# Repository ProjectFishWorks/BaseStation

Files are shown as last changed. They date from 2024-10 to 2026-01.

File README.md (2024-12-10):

# BaseStation

The base station acts as the controller for the Fish Sense system. It connects to the devices via CAN Bus, and provides power to them. It then connects to the web app over WiFi and the MQTT protocol. It also sends email alerts and provides a basic user interface using buttons, LEDs, a buzzer, and a display.

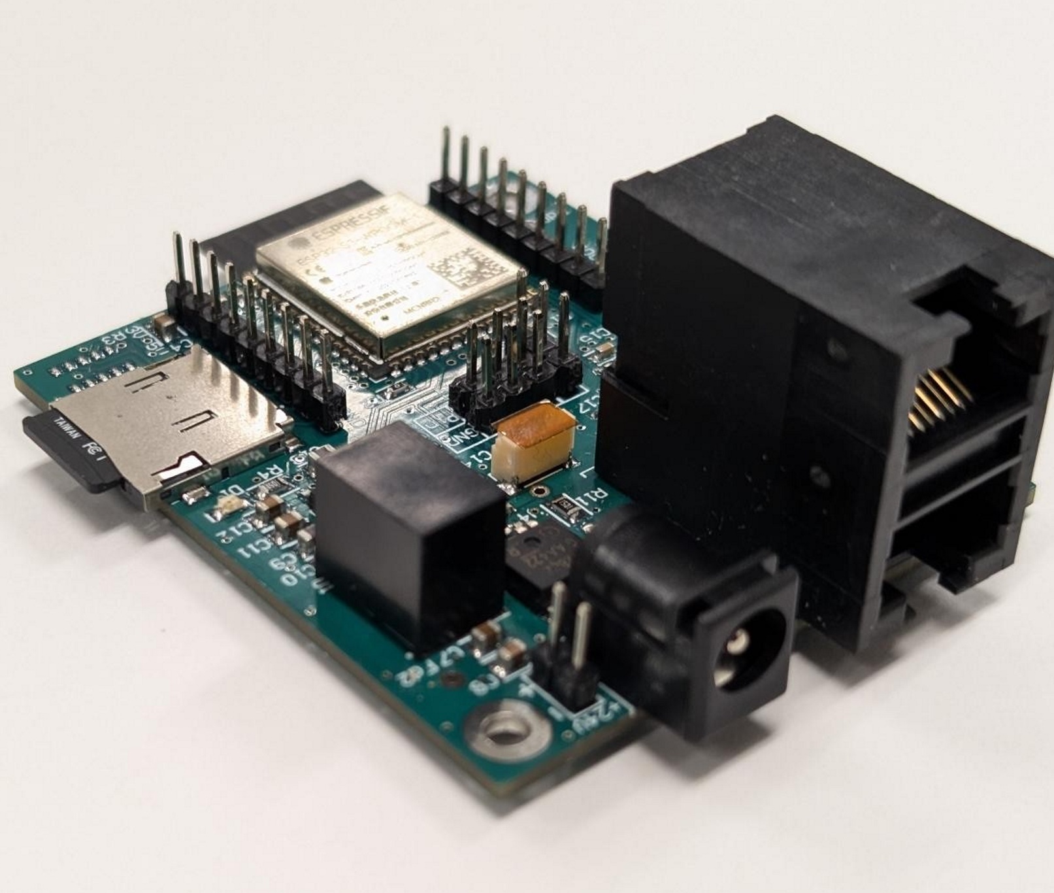
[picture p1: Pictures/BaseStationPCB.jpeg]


## Hardware

The base station is powered by the ESP32 S3 WROOM 1 module. The Microchip MCP2551 is used for the CAN Bus interface. Power is provided via a external 24V DC input. This 24V power is provided to the connected devices as well. The 24V going to the devices is switched to allow for controlled power up of the device network. It is also monitored using a current monitroing IC.

## MQTT CAN Bus data format

### Data outgoing from the base station

When data is received from the CAN Bus, it is sent to the web app over MQTT using the following format:

#### Topic:  
``` 
out/[System ID]/[Base Station ID]/[Node ID]/[Message ID] 
```

* System ID: The ID of the system/user. A system can contain several base stations.
* Base Station ID: The ID of the base station.
* Node ID: The ID of the node(attached to the base station) that the message is from.
* Message ID: A unique ID for the message type being sent.

#### Payload:  
``` 
{"data": [Data], "timestamp": [Timestamp]} 
```
* Data: The from the CAN Bus message.
* Timestamp: The time the message was received by the base station.

### Data incoming to the base station

When data is sent from the web app to the base station(to be sent to devices via CAN Bus), it is sent using the following format:

#### Topic:  
``` 
in/[System ID]/[Base Station ID]/[Node ID]/[Message ID] 
```

#### Payload:  
``` 
{"data": [Data], "timestamp": [Timestamp]} 
```

(Other JSON fields are added due to issues with the way the web app sends out MQTT data and are not used by the base station)

## MQTT History Request Format

The web app can request a specific numbers of hours(going back from the current time) for a specific node and message ID with the following format:

#### Topic:  
``` 
historyIn/[System ID]/[Base Station ID]/[Node ID]/[Message ID] 
```

#### Payload:  
``` 
{"hours": [Hours as a interger]} 
```

(Other JSON fields are added due to issues with the way the web app sends out MQTT data and are not used by the base station)

Once the base station receives this request, it will send out the requested data, one hour per MQTT message, in the following format:

#### Topic:  
``` 
historyOut/[System ID]/[Base Station ID]/[Node ID]/[Message ID]/[Hour] 
```

* Hour: The hour of the data being sent. The time is the format: "YYYYMMDDHH"

#### Payload:  
``` {"hour": [Hour Timestamp], 
    "systemID": [System ID],
    "baseStationID": [Base Station ID],
    "nodeID": [Node ID],
    "messageID": [Message ID],
    "history": [{"time": [Message Time], "data": [Message Data]}, ...]}
```
* Hour Timestamp: The unix timestamp(UTC) of the hour being sent. The timestamp of the newest hour being sent will be the current time. Each hour in the past will be the current time minus the number of hours requested.
* History: An array of messages for that hour.
* Message Time: The time the message was received by the base station.
* Message Data: The data from the CAN Bus message.

The number of messages in the "history" array will depend on the number of messages stored for that hour and the number of hours being requested. The more hours requested, the less messages per hour will be sent.

## Device manifest format

The device manifest is used to to communicate the devices connected to the base station to the web app. It also store a human-readable name for each device and the base station itself. When a base station boots up, it sends out its manifest, that is stored in the base station flash, to the web app in the following format:

#### Topic:  
```
manifestOut/[System ID]/[Base Station ID]
```

#### Payload:  
```
{"SystemID":0,
"BaseStationID":0,
"BaseStationName":"Capstone Demo Tank",
"Devices":[{"NodeID":[Node ID],"DeviceType":"[Device Type]]","DeviceName":[Device Name]}, ... ]}

```

* BaseStationName: The human-readable name of the base station(string).
* Devices: An array of devices connected to the base station.
    * NodeID: The ID of the device.
    * DeviceType: The type of device. This must match the device pages and widgets in the web app. Widgets: ```[Device Type]Widget.razor ```, Pages: ```[Device Type]Page.razor```
    * DeviceName: The human-readable name of the device(string).

When the web app wants change the manifest, it sends the new manifest to the base station in the following format:

#### Topic:  
```
manifestIn/[System ID]/[Base Station ID]
```

#### Payload:  
```
{"SystemID":0,
"BaseStationID":0,
"BaseStationName":"Capstone Demo Tank",
"Devices":[{"NodeID":[Node ID],"DeviceType":"[Device Type]]","DeviceName":[Device Name]}, ... ]}

```

The base station will then store this new manifest in its flash and send it back to the web app using the same format as when it boots up.

## WiFi Manager Custom Parameters

The base station uses the WiFi Manager library to manage WiFi connections. The following custom parameters are also used:

* MQTT Server: The IP address of the MQTT server.
* MQTT Username: The username for the MQTT server.
* MQTT Password: The password for the MQTT server.
* Email Recipient: The email address to send alert emails to.
* Email Recipient Name: The name of the email recipient.

These parameters are stored in the base station flash in a JSON file.

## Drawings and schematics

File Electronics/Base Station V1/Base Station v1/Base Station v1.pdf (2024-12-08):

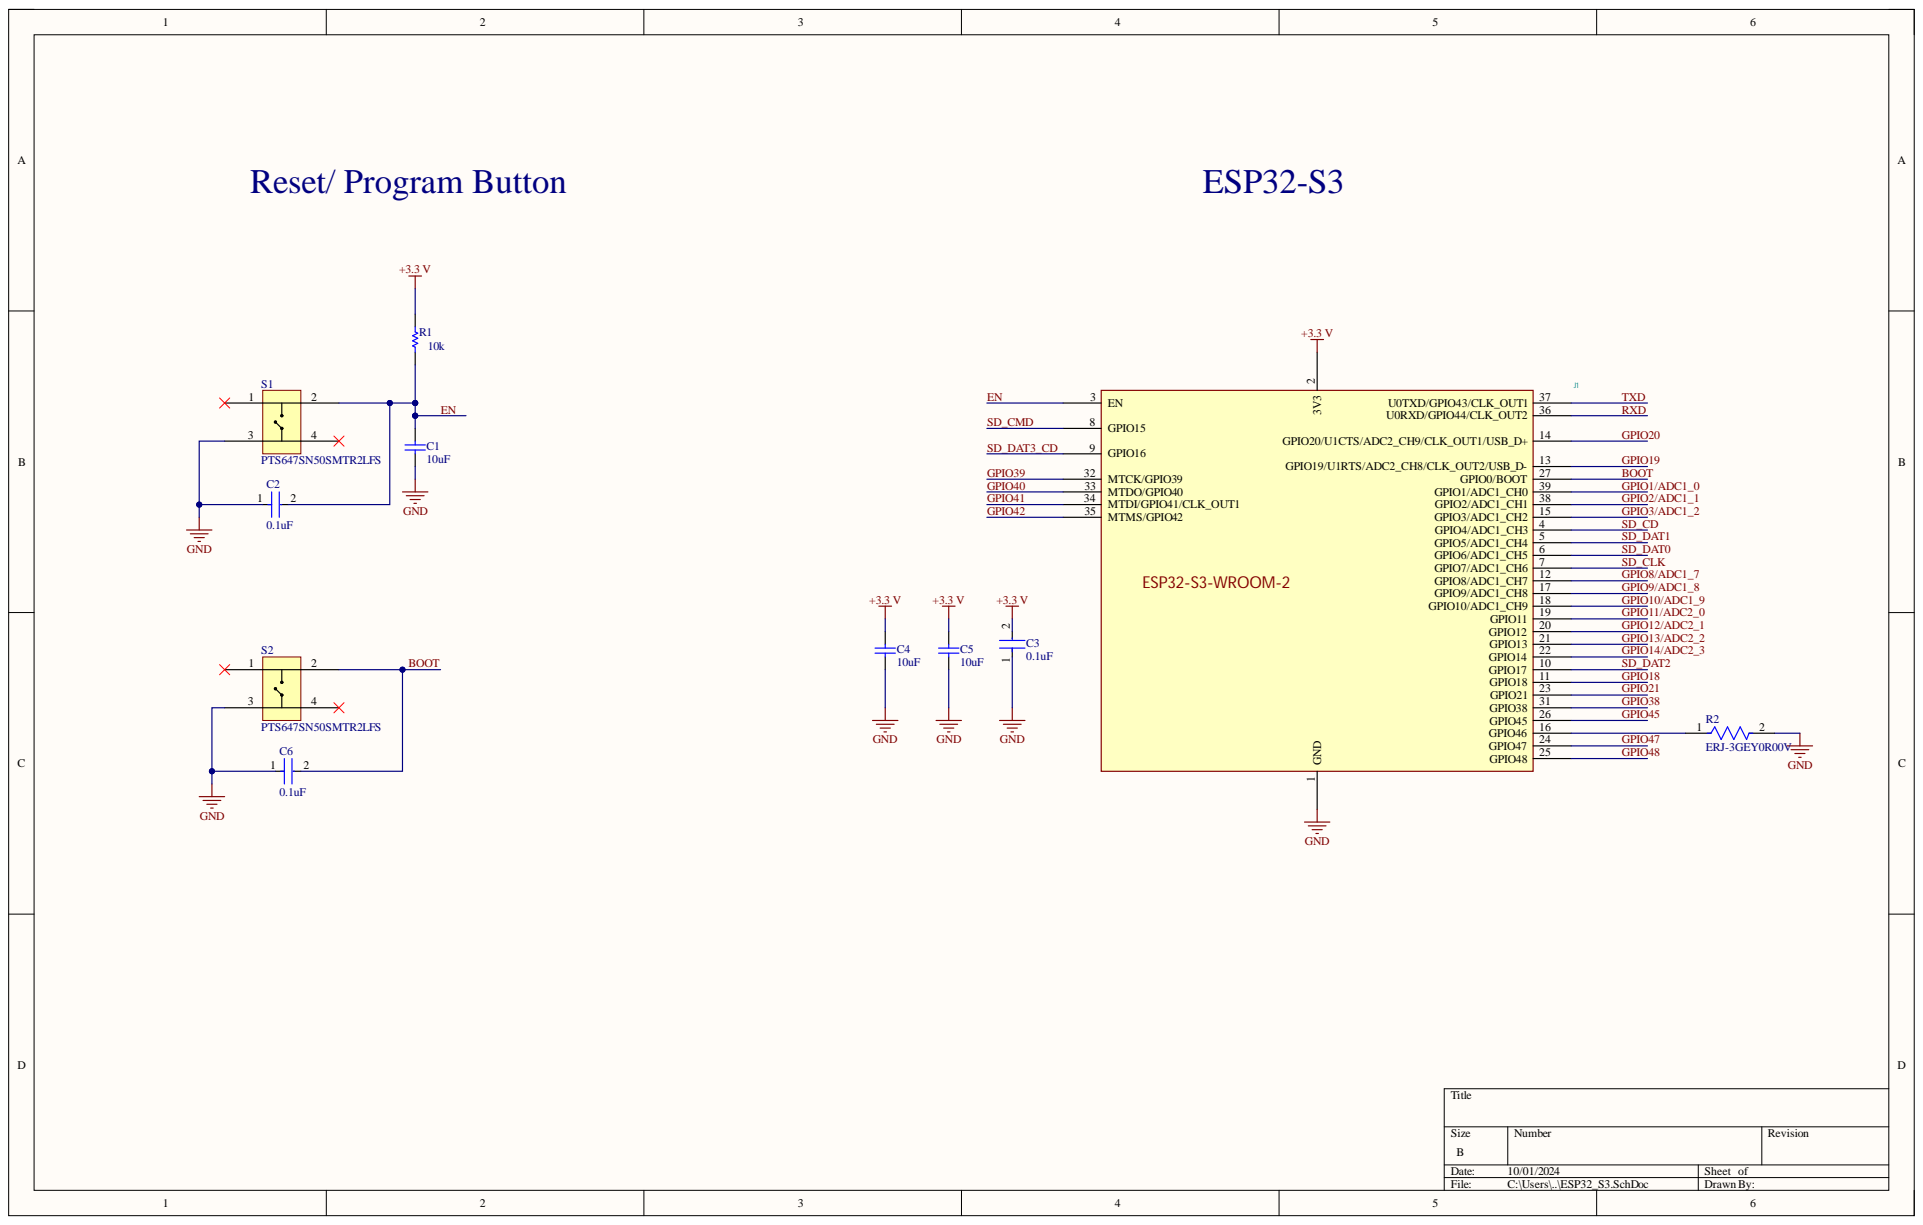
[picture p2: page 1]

Si z e | Num b er | Revi s i on

e : 10/01/ 20 24 | Sheet of
Fi l e : C : \U ser s \..\ ESP32_S3.Sch Do c | D rawn By:

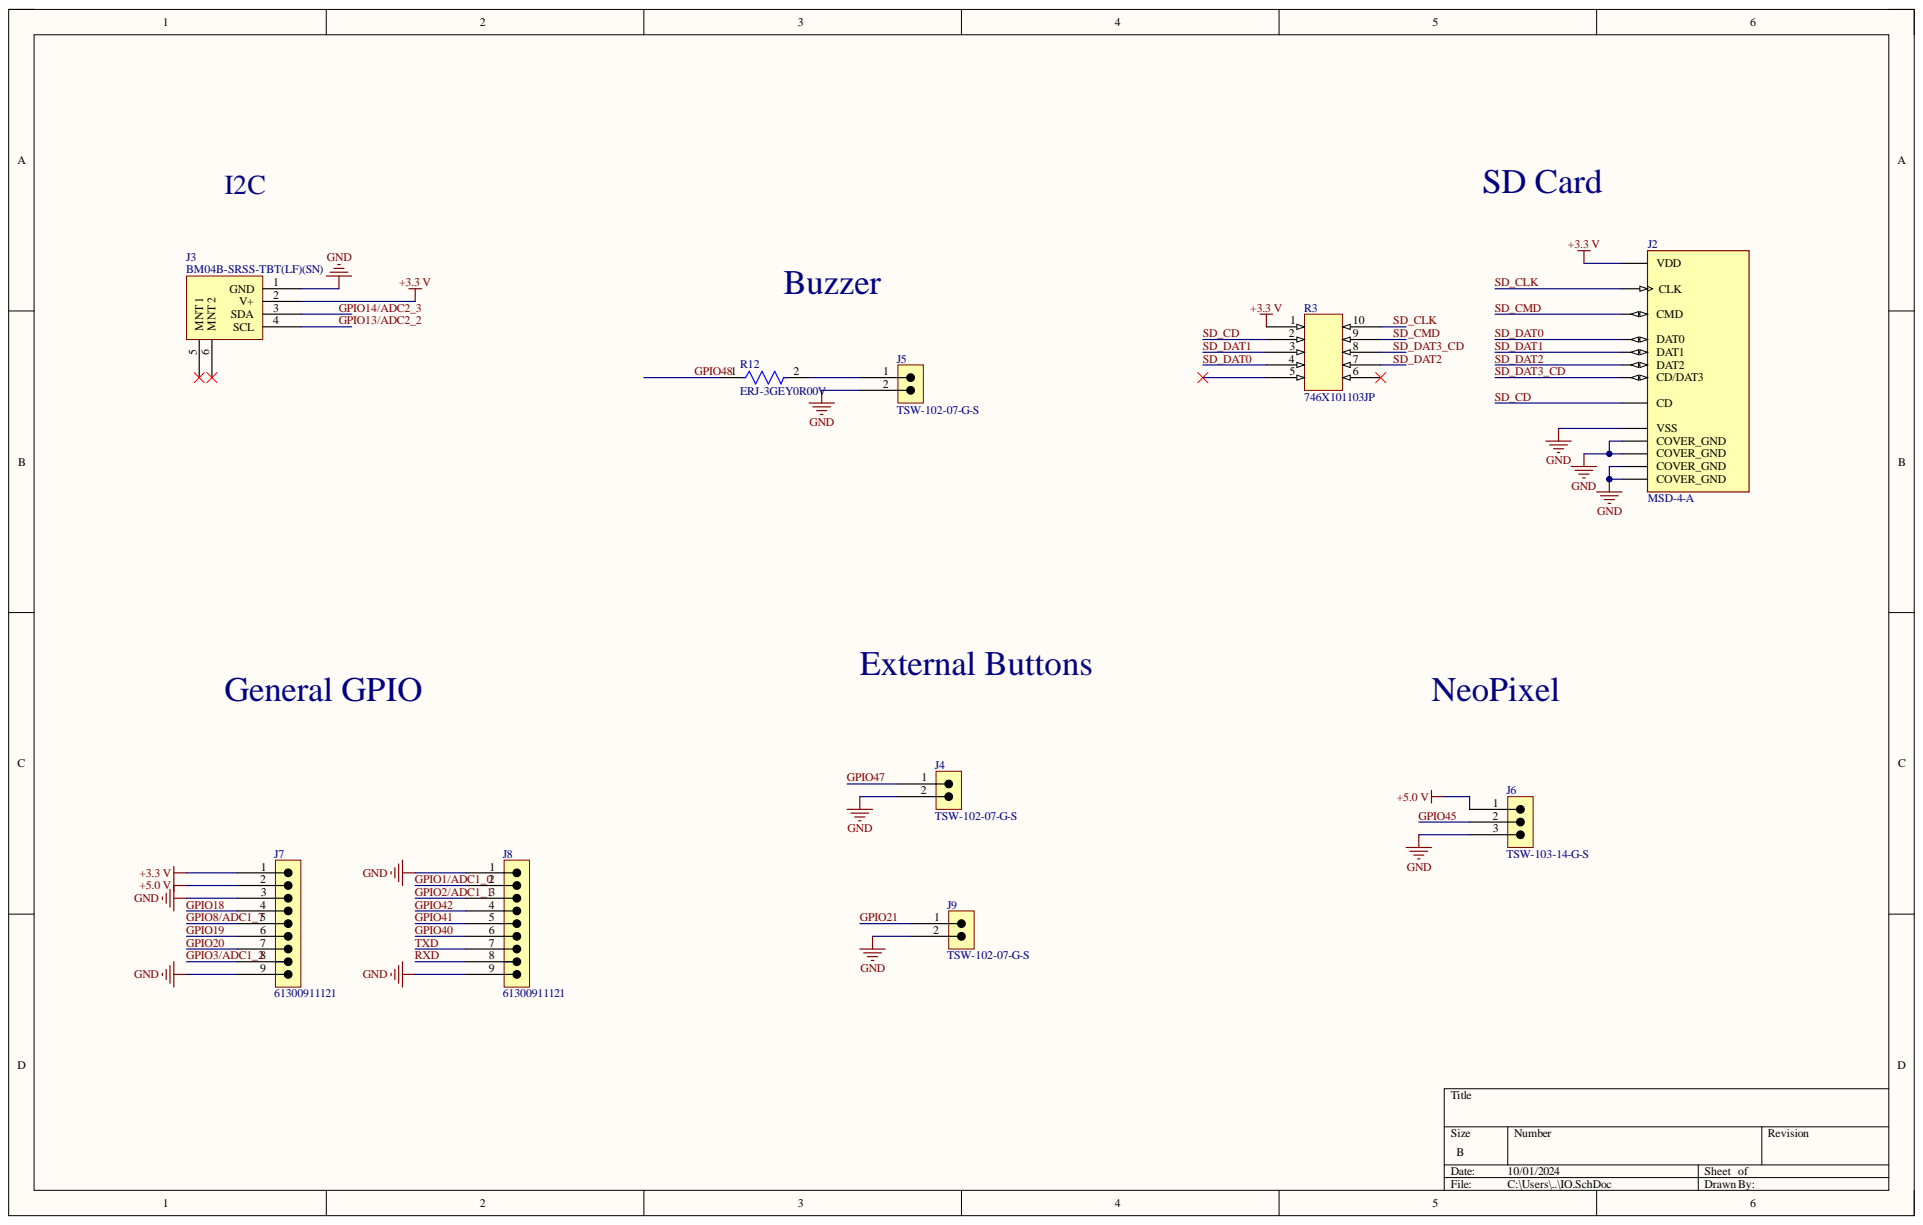
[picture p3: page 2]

BM04B-SRSS-TBT(LF)(SN)

Size B | Number | Revision

Date: 10/01/2024 | Sheet of
File: C:\Users\..\IO.SchDoc | Drawn By:

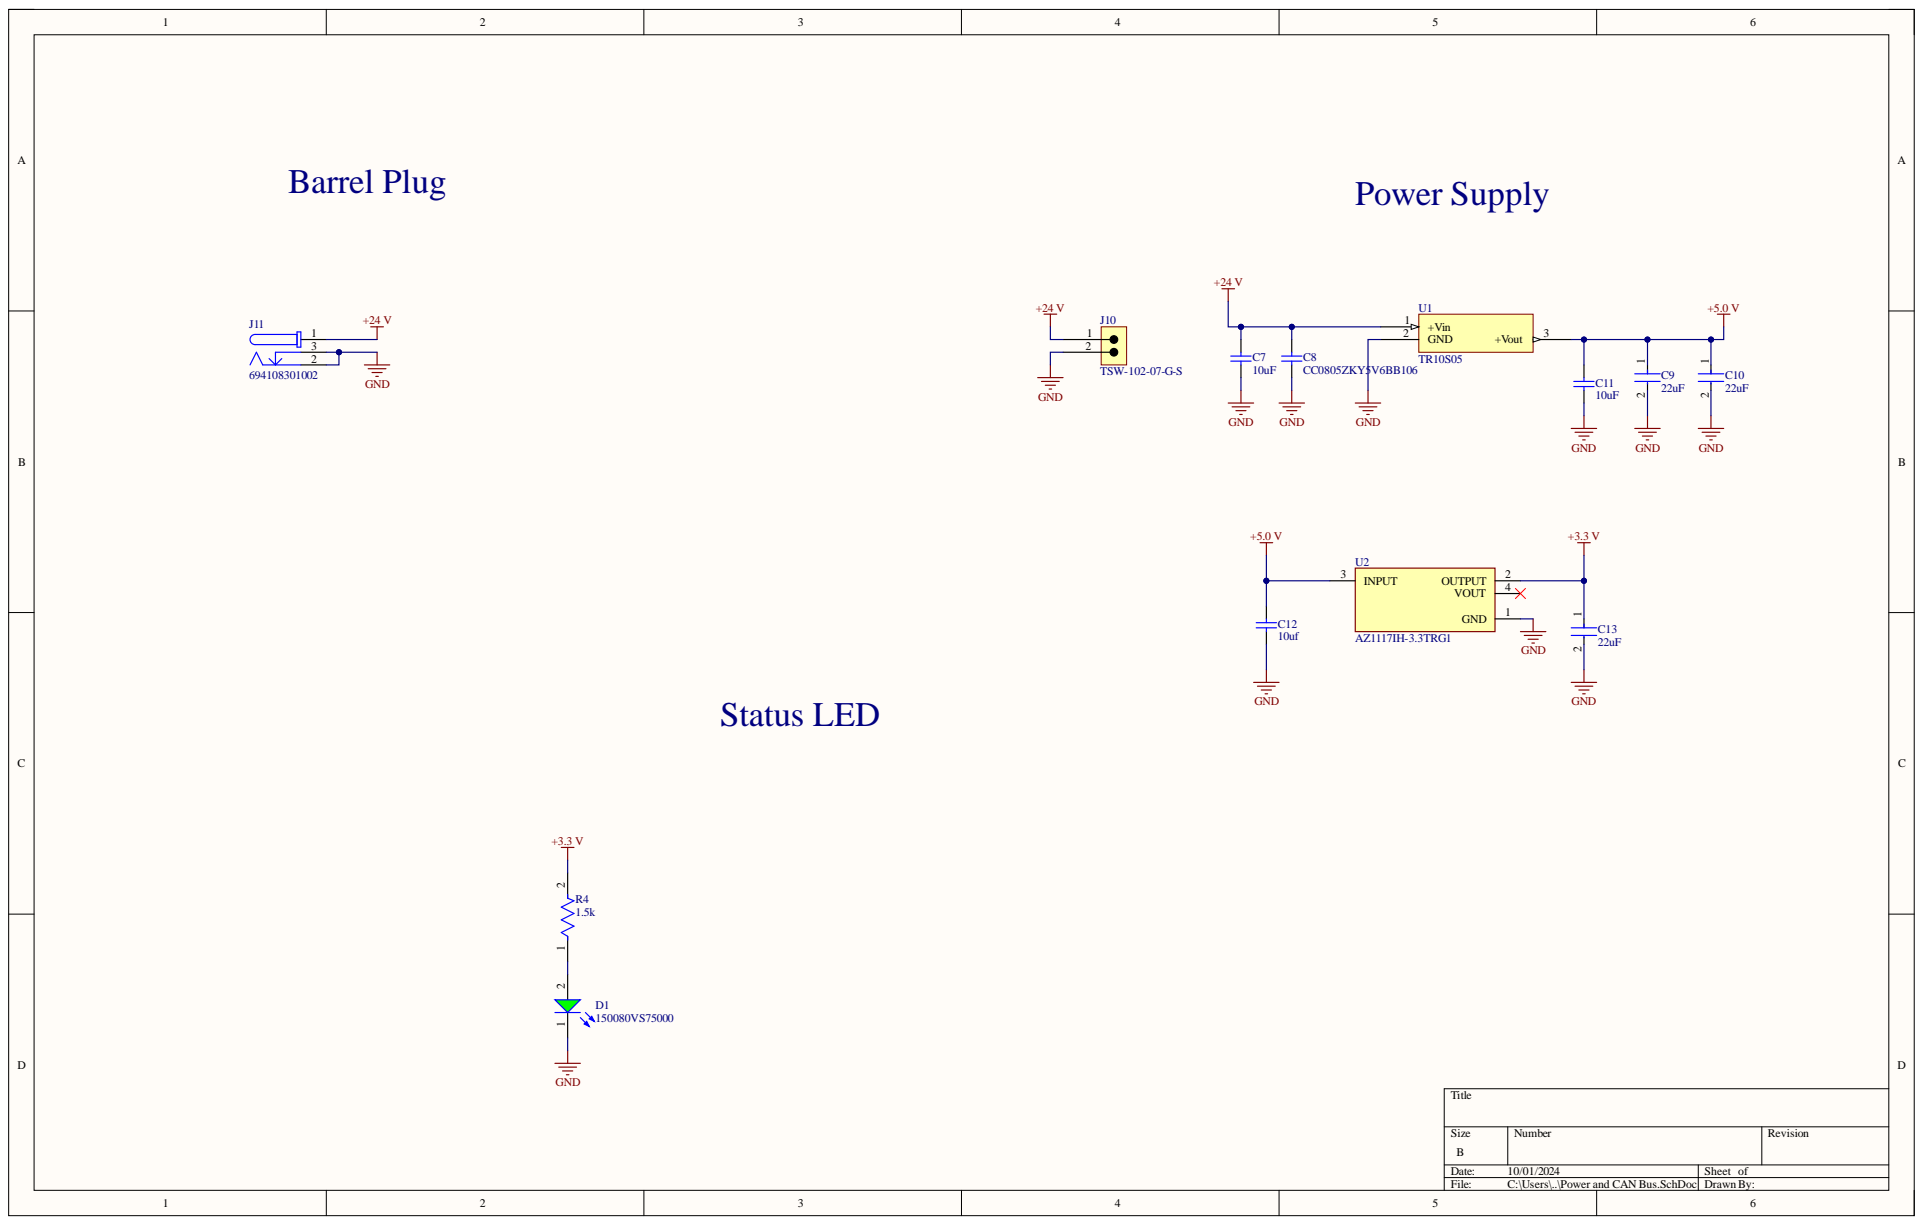
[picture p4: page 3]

Si z e | Num b er | Revi s i on

e : 10/01/ 20 24 | Sheet of
Fi l e : C : \U ser s \..\Power and C A N Bus.SchDoc | D rawn By:

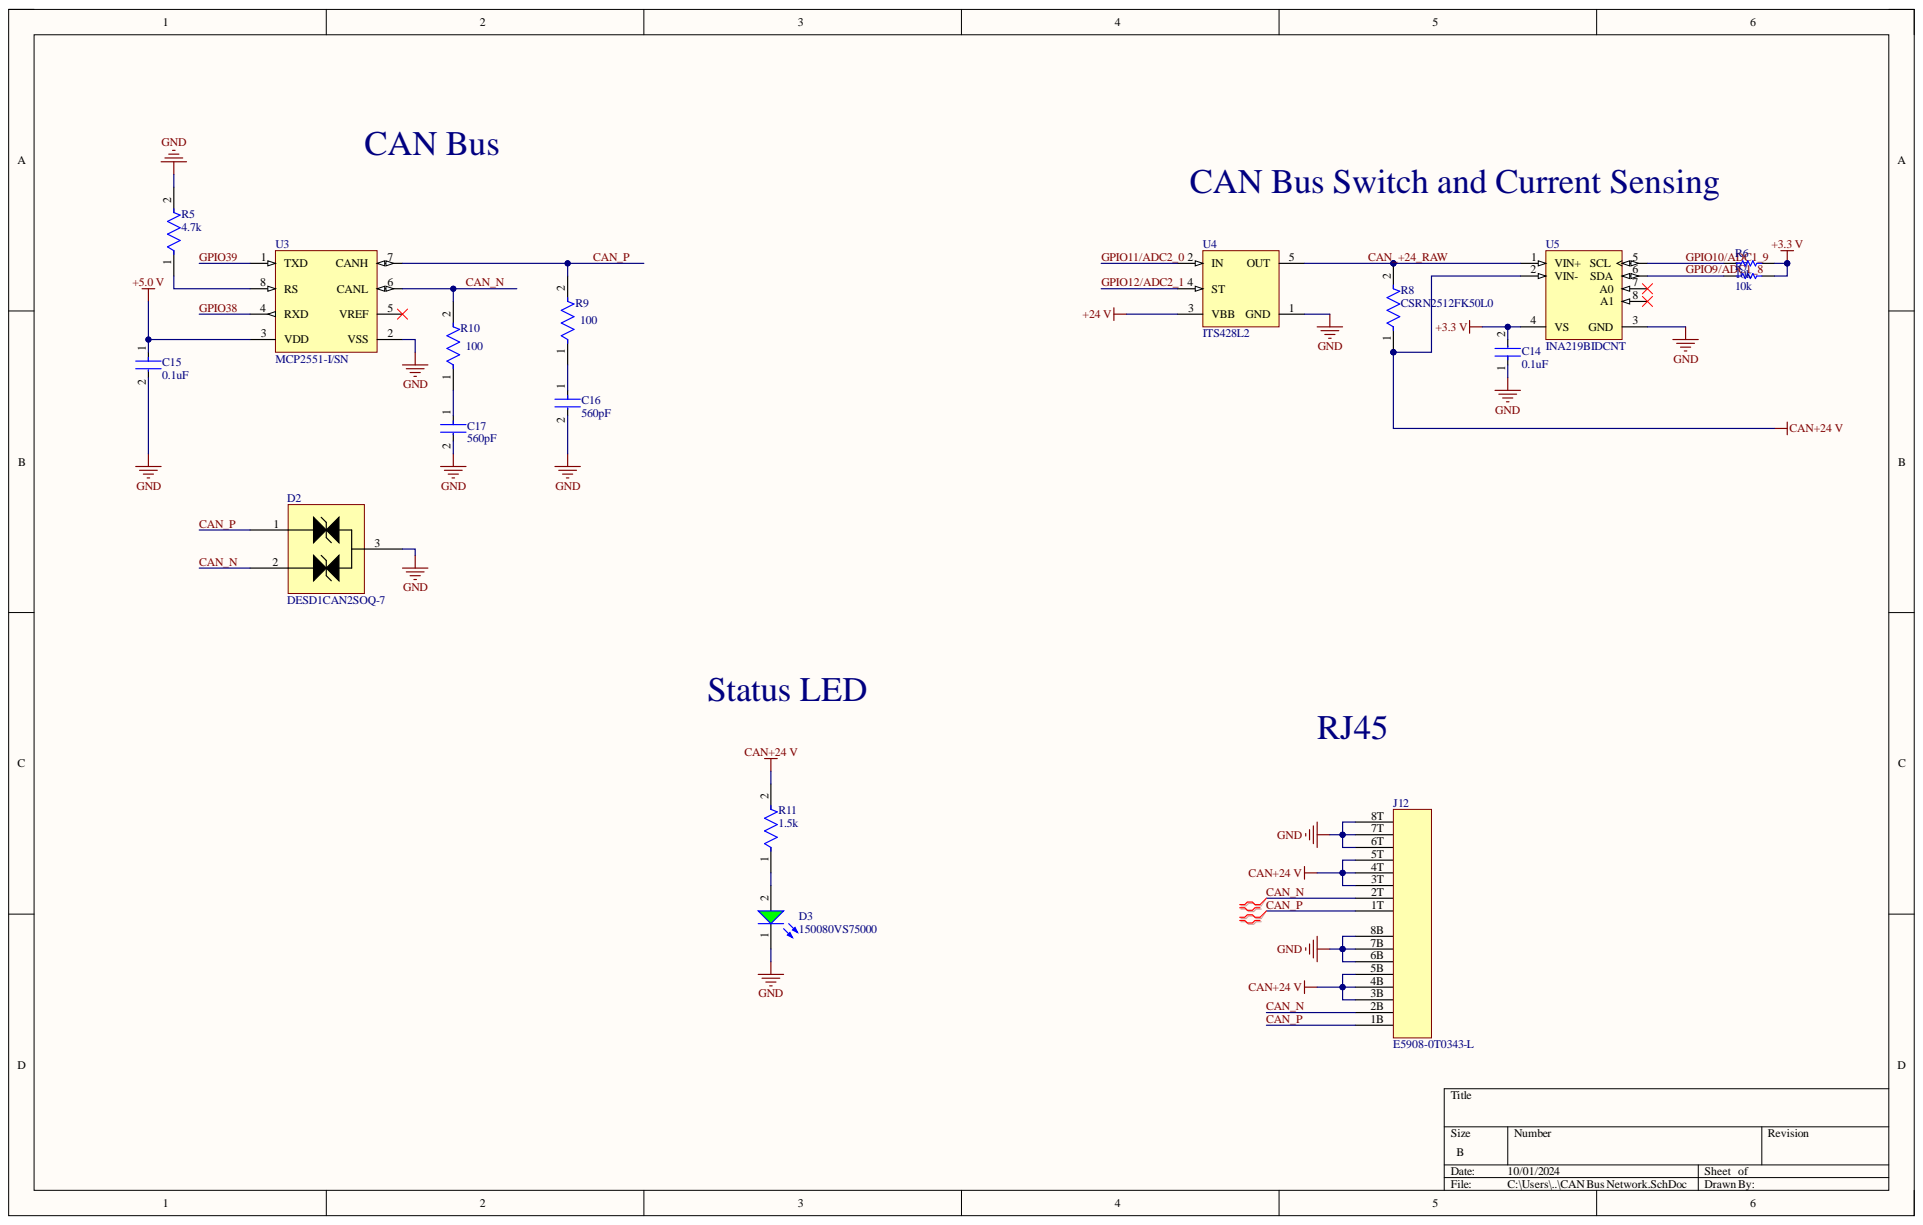
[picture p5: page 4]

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
Si z e | Num b er | Revi s i on

e : 10/01/ 20 24 | Sheet of
Fi l e : C : \U ser s \..\ C A N Bus Net work.SchD o c | D rawn By:

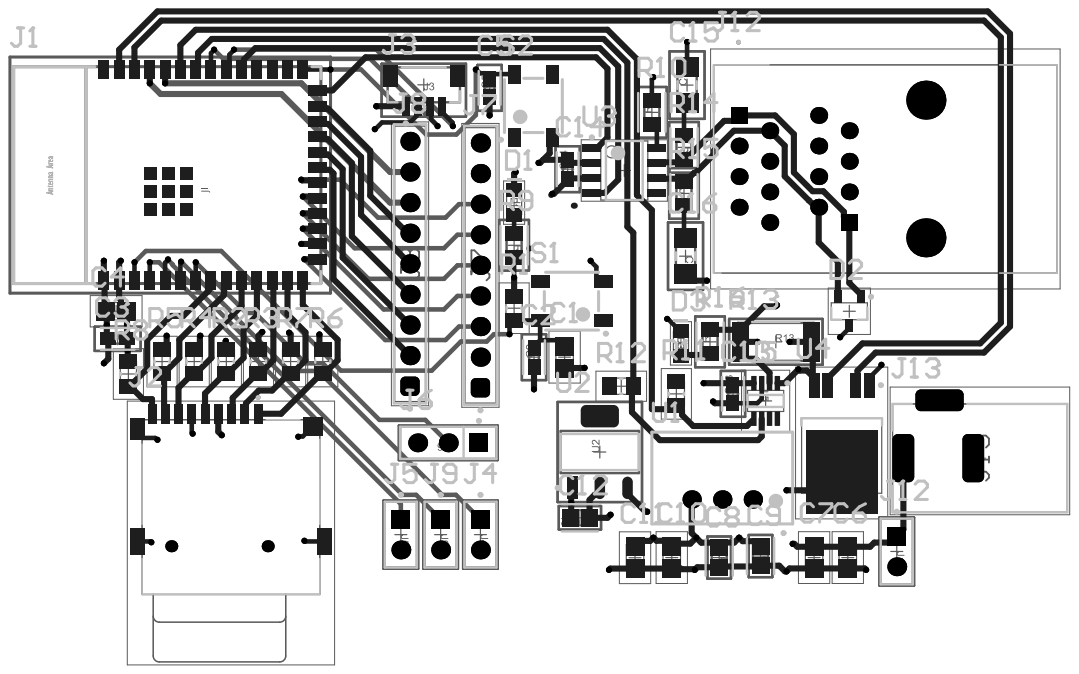
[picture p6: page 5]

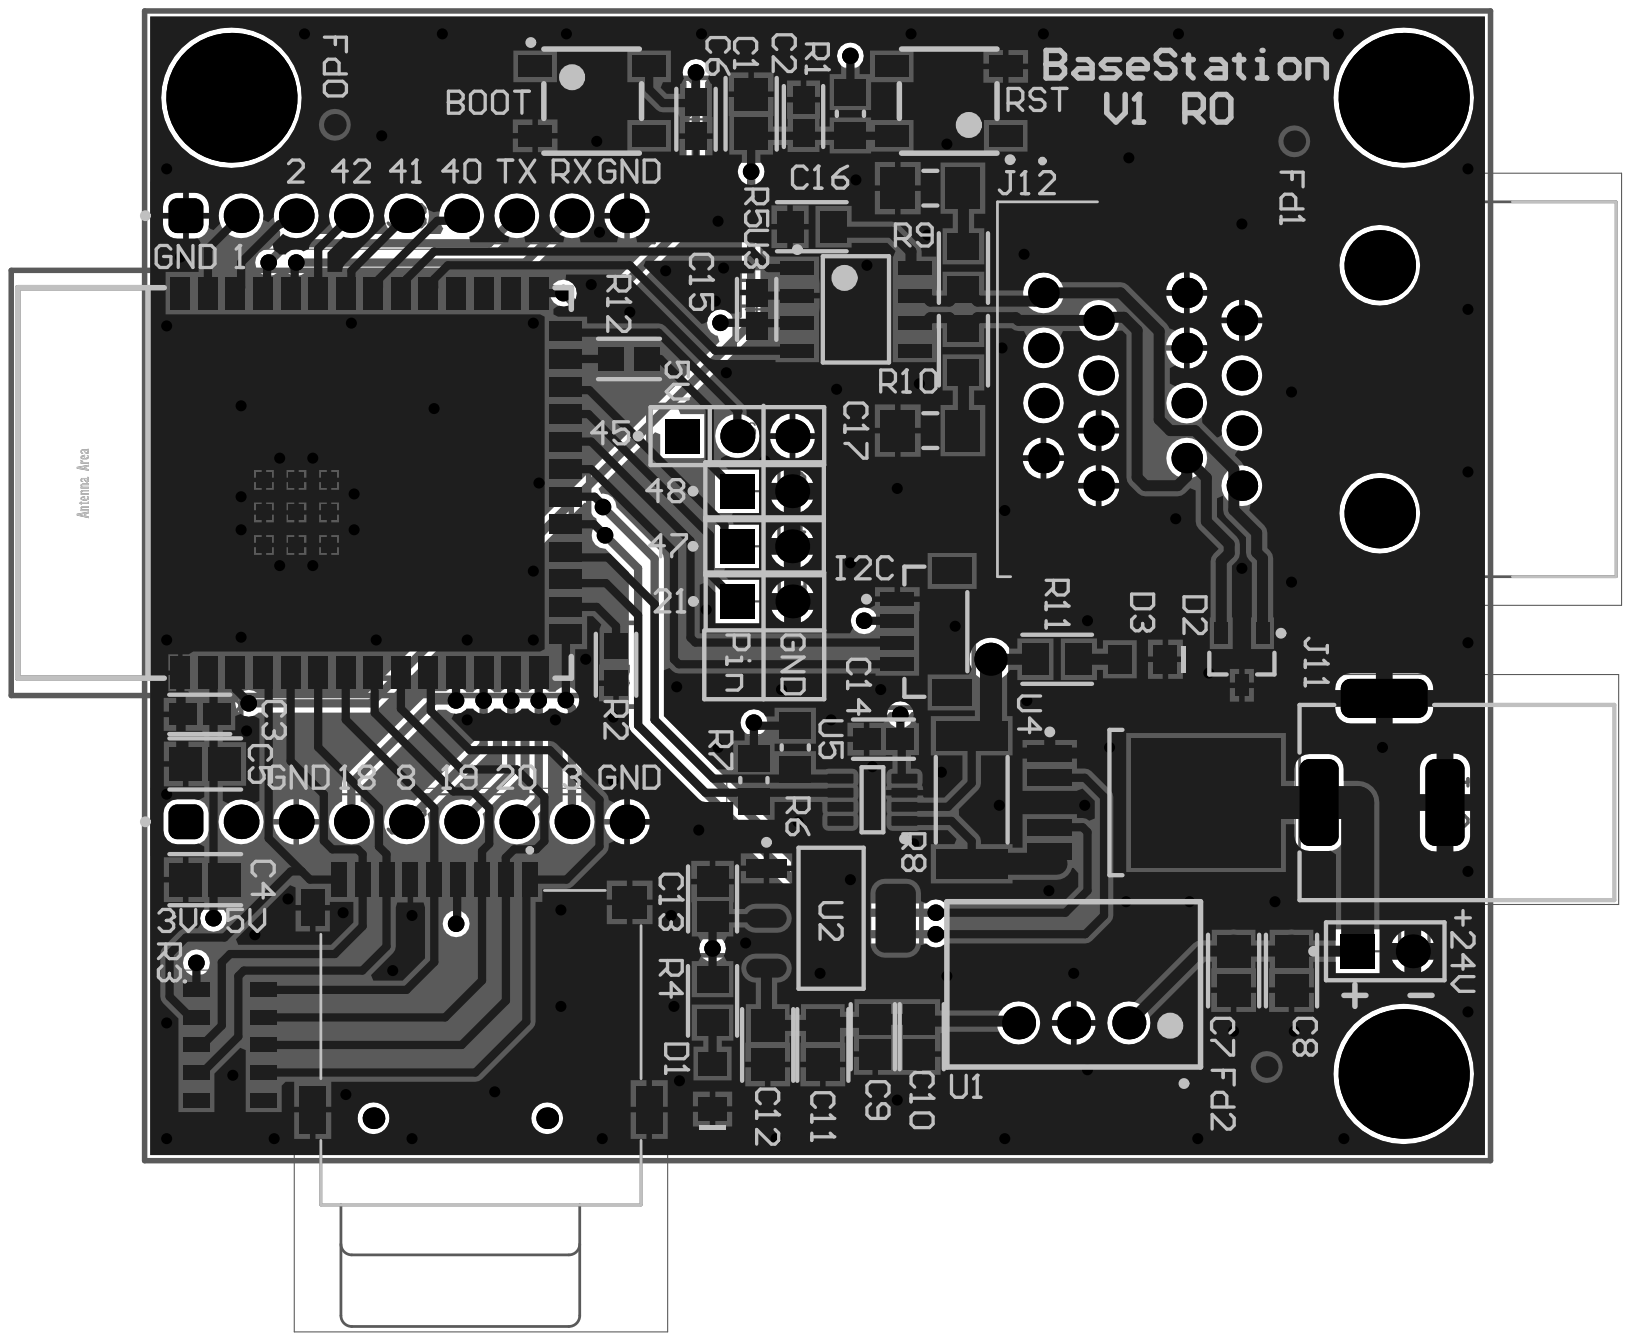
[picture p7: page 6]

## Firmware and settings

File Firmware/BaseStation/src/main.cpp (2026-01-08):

// Imports
#include <Arduino.h>
#include "credential.h"
#include <WiFi.h>
#include <WiFiManager.h> // https://github.com/tzapu/WiFiManager
#include "WiFiClientSecure.h"
#include <BaseStationCore.h>
#include <PubSubClient.h>
#include <ArduinoJson.h>
#include "emailClient.h"
#include <dataLogging.h>
#include <Adafruit_NeoPixel.h>
#include <Adafruit_GFX.h>
#include <Adafruit_SSD1306.h>
#include <SPI.h>
#include <Wire.h>
#include <Adafruit_INA219.h>
#include "FS.h"
#include <LittleFS.h>
#include <time.h>

#include "deviceAuthorization.h"
#include "auth0DeviceAuthorization.h"
#include "mqttLogin.h"

// Constants-----------------------------------------------------------------------------------------------------------------------

// #define DEBUG // Comment out to disable debug messages
// #define DEBUG_BaseStationState // Comment out to disable debug messages
// #define DEBUGTime // Comment out to disable debug messages

#define maxPWM 255 // Maximum PWM value for the LED

// CAN Bus message IDs for base station
#define NODE_ID 0
#define UPDATE_UNIX_TIMESTAMP_MESSAGE_ID 2000
#define UPDATE_TIMEZONE_OFFSET_MESSAGE_ID 2001
#define LED_BRIGHTNESS_MESSAGE_ID 2500
uint64_t LEDBrightness; // Brightness of the NeoPixel
float LEDBrightness_float;
#define IS_ERRORS_MESSAGE_ID 2501
#define IS_NO_ERRORS_MESSAGE_ID 2502
#define RESET_ALERTS_MESSAGE_ID 2503

// Error message flags
uint64_t isErrors;
uint64_t isNoErrors;

// Time
char localTime[64];                                  // Local time string
uint64_t localTimeZoneOffset = 8;                    // Timezone offset
String localTimeZone = "UTC+" + localTimeZoneOffset; // Timezone string
char buf_localTimeZone[8];                           // Char array Buffer for timezone string
struct tm timeinfo;
time_t UNIXtime;
uint64_t lastRTCUpdate = millis();

// CAN Bus message IDs for warnings and alerts
#define WARN_ID 0x384  // 900
#define ALERT_ID 0x385 // 901

// TODO: Temp until final versioning system is implemented
#define baseStationFirmwareVersion 0.01

// TODO: Manual system ID and base station ID, temp untils automatic paring is implemented
#define SYSTEM_ID 0x00      // Leave
#define BASESTATION_ID 0x03 // change for desired base station ID -> 0 = Sebastien Pacific Terrarium, 4 =Kayleb's test station, 3 = Kayleb's Reef

// TODO: MQTT Credentials - temp until these are added to WiFiManager system
char mqtt_server[255] = "projectfishworks.ca";
char mqtt_username[255] = "fishworks-dev";
char mqtt_password[255] = "F1shworks!";

// char email_recipient[255] = "sebastien@robitaille.info";
// char email_recipient_name[255] = "Sebastien Robitaille";

char email_recipient[255] = "kayleb_s@hotmail.com";
char email_recipient_name[255] = "Kayleb Stetsko";

MQTTLogin mqttLogin;

String userID;

TaskHandle_t xMQTTloop = NULL;

// TODO: add timezone support to WiFiManager
#define ntpServer "pool.ntp.org"
#define gmtOffset_sec 0
#define daylightOffset_sec 0

#define manifestFileName "/manifest.json"

#define mqttConfigFileName "/config.json"

// flag for saving data
bool shouldSaveConfig = false;

// Screen Savers
long lastInput;
int lastPosition = 1;

// Buzzer Control
int antiBuzzer = 0;

// NeoPixel Setup Stuffs
#define PIN 45       // On Trinket or Gemma, suggest changing this to 1
#define NUMPIXELS 2  // Popular NeoPixel ring size
#define DELAYVAL 500 // Time (in milliseconds) to pause between pixels
int errorQueued = 0; // Flag to indicate if an error has been queued for the NeoPixel
int nightMode = 0;   // Flag to indicate if night mode is enabled

Adafruit_NeoPixel pixels(NUMPIXELS, PIN, NEO_RGB + NEO_KHZ800);

// LCD Screen Setup Stuffs
#define SCREEN_WIDTH 128    // OLED display width, in pixels
#define SCREEN_HEIGHT 64    // OLED display height, in pixels
#define OLED_RESET -1       // Reset pin # (or -1 if sharing Arduino reset pin)
#define SCREEN_ADDRESS 0x3C ///< See datasheet for Address; 0x3D for 128x64, 0x3C for 128x32
#define Fishy_HEIHT 16
#define Fishy_WIDTH 32
#define LOGO_HEIGHT 44
#define LOGO_WIDTH 64
bool screenSaverRunning;
int LCD_SDA = 13;
int LCD_SCL = 14;
static const unsigned char PROGMEM fishy_bmp[] =
    /**
     * Made with Marlin Bitmap Converter
     * https://marlinfw.org/tools/u8glib/converter.html
     */
    {
        B00100000, B00000000, B00000000, B00111000,
        B00000000, B00010000, B00000000, B00101000,
        B00000000, B00001000, B00000000, B00111000,
        B00000011, B00001100, B00000000, B00000000,
        B00000001, B10011111, B00000001, B10000000,
        B00111001, B10100000, B10000001, B10000000,
        B00101001, B11000001, B01000000, B00000000,
        B00111000, B10000000, B00100000, B00000000,
        B00000001, B11000000, B01000000, B00000000,
        B00000001, B10100000, B10000100, B00000000,
        B00000001, B10011111, B00000000, B00000000,
        B00000011, B00001100, B00000000, B00000000,
        B01100000, B00001000, B00000000, B11110000,
        B01100000, B00010000, B00000000, B10010000,
        B00000000, B00000000, B10000000, B10010000,
        B00000000, B00000000, B00000000, B11110000};
static const unsigned char PROGMEM logo_bmp[] =
    /**
     * Made with Marlin Bitmap Converter
     * https://marlinfw.org/tools/u8glib/converter.html
     */
    {
        B00000000, B00000000, B00000000, B11111111, B11111100, B00000000, B00000000, B00000000,
        B00000000, B00000000, B00000111, B00000011, B00000011, B10000000, B00000000, B00000000,
        B00000000, B00000000, B00011000, B11110000, B01111100, B11100000, B00000000, B00000000,
        B00000000, B00000000, B00100011, B00001111, B11000011, B00110000, B00000000, B00000000,
        B00000000, B00000000, B01001100, B11100000, B00011100, B11011000, B00000000, B00000000,
        B00000000, B00000000, B01110011, B00011111, B11100011, B00110000, B00000000, B00000000,
        B00000000, B00000000, B00000100, B11000000, B00011100, B10000000, B00000000, B00000000,
        B00000000, B00000000, B00001111, B00011100, B11100110, B10000000, B00000000, B00000000,
        B00000000, B00000000, B00000000, B01000111, B10011001, B00000000, B00000000, B00000000,
        B00000000, B00000000, B00000000, B10011000, B01100100, B00000000, B00000000, B00000000,
        B00000000, B00000000, B00000000, B11100111, B00011000, B00000000, B00000000, B00000000,
        B00000000, B00000000, B00000000, B00001100, B10000000, B00000000, B00000000, B00000000,
        B00000000, B00000000, B00000000, B00001100, B10000000, B00000000, B00000000, B00000000,
        B00000000, B00000000, B00000000, B00000111, B10000000, B00000000, B00000000, B00000000,
        B00000000, B00000000, B00000000, B00000000, B00000000, B00000000, B00000000, B00000000,
        B00000001, B11111111, B11111111, B11111111, B11111111, B11111111, B11111111, B11110000,
        B00000001, B10000000, B00000000, B00000000, B00000000, B00000000, B00001100, B00110000,
        B00000001, B10111100, B00110000, B00000000, B00000111, B11110000, B00001000, B00110000,
        B00000001, B10000000, B00000000, B01111111, B00000000, B00000011, B11111111, B11110000,
        B00000001, B00011000, B00000000, B11010011, B11101111, B11000000, B00000000, B00010000,
        B00000001, B00011000, B00000001, B10111101, B11111101, B00110000, B00000000, B00010000,
        B00000001, B00000000, B00000111, B10000000, B11111001, B01001000, B00000000, B00010000,
        B00000001, B00000000, B00011100, B00000000, B00011111, B11100100, B00001110, B00010000,
        B00000001, B00000000, B11100100, B00000000, B00010001, B11111100, B00110111, B00010000,
        B00000001, B00000001, B00110010, B00000000, B00010000, B00111100, B11111001, B10010000,
        B00000001, B00000110, B10011011, B00000000, B00010000, B00011101, B11111001, B10010000,
        B00000001, B00001101, B11101001, B00000000, B00000000, B00010100, B01111001, B10010000,
        B00000001, B10011101, B11101001, B00000000, B00010000, B00010100, B01111111, B10010000,
        B00000001, B10011110, B11001001, B00011111, B10010000, B00010100, B01111001, B10010000,
        B00000001, B10011010, B00001001, B01111100, B11010000, B00011100, B11111101, B10010000,
        B00000001, B10001110, B00001001, B01011100, B01010000, B00011111, B11100001, B10110000,
        B00000000, B10000111, B00110010, B01111100, B01010000, B01111100, B11100001, B00110000,
        B00000000, B10000000, B11100100, B00011111, B11010011, B11111100, B00111011, B00100000,
        B00000000, B11000000, B00111100, B00000011, B11111111, B11100100, B00001110, B00100000,
        B00000000, B01000000, B00000011, B11111111, B11111111, B10001000, B00000000, B01000000,
        B00000000, B00100000, B00000001, B11110110, B00111110, B01110000, B00000000, B11000000,
        B00000000, B00110000, B00000000, B11100010, B00000011, B10000000, B00000000, B10000000,
        B00000000, B00011000, B00000000, B01110010, B00000000, B00000000, B00000001, B00000000,
        B00000000, B00001100, B00000000, B00011110, B00000000, B00000000, B00000010, B00000000,
        B00000000, B00000111, B11110000, B00000000, B00000111, B11110000, B01111100, B00000000,
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

Adafruit_SSD1306 display(SCREEN_WIDTH, SCREEN_HEIGHT, &Wire, OLED_RESET);

// Current Sense Setup Stuffs
float shuntvoltage = 0;
float busvoltage = 0;
float current_mA = 0;
float loadvoltage = 0;
float power_mW = 0;
int CUR_SDA = 9;
int CUR_SCL = 10;

Adafruit_INA219 ina219(0x4A); // I2C address 0x4A or

// Struct for Error Queue
uint8_t errorsQueued = 0;
typedef struct
{
  int16_t nodeID;
  uint8_t isWarning;
  uint8_t isSilenced = 1;
  uint8_t isCleared = 1;
} UIAlertData;

// Array of AlertData
UIAlertData alertQueue[50];

// Base Station Core - temp usage coustom code for base station is created
BaseStationCore core;
uint8_t baseStationState = 0;

// WiFi client
WiFiClientSecure espClient;

// MQTT client
PubSubClient mqttClient(espClient);

// TODO: Log file write queue - not working right now
QueueHandle_t log_file_queue;
#define LOG_FILE_QUEUE_LENGTH 10

// Global data fix for pointer issues, TODO fix this shit
// uint64_t data = 0;

// Put Functon Declarations here -----------------------------------------------------------------------------------
void saveConfigCallback();
void mqttLoop(void *_this);
void neoPixelTask(void *parameters);
void mainUIDisplayTask(void *parameters);
void sendWarningToQueue();
void updateRTC(void *parameters);
void receivedCANBUSMessage(uint8_t nodeID, uint16_t messageID, uint8_t logMessage, uint64_t data);
void MQTTConnect();
void MQTTdisconnect();
void receivedMQTTMessage(char *topic, byte *payload, unsigned int length);
void annoyingBuzz();
void testCurrentSense();
void SendMQTTMessage(uint8_t _systemID, uint8_t _baseStationID, uint8_t _nodeID, uint16_t _messageID, uint64_t _data);
String getTopicComponent(String &topic, int componentIndex);
void handleInternalMessage(int messageID, uint64_t data);
void resetAlerts();
void handleHistoryMessage(int nodeID, int messageID, uint64_t data);
void handleManifestMessage(JsonDocument &doc, byte *payload, unsigned int length);
void sendTimezoneOffsetMessage(uint64_t data);

// Authrise the device

DeviceAuthorization *deviceAuthorization;

Auth0DeviceAuthorization auth0DeviceAuthorization = Auth0DeviceAuthorization();

// Function that is called when a CAN Bus message is received
void receivedCANBUSMessage(uint8_t nodeID, uint16_t messageID, uint8_t logMessage, uint64_t data)
{
  Serial.println("Message received callback");
  Serial.println("Sending message to MQTT");

  // Create the MQTT topic string
  String topic = userID + "/out/" + String(SYSTEM_ID) + "/" + String(BASESTATION_ID) + "/" + String(nodeID) + "/" + String(messageID);

  // Allocate the JSON document
  JsonDocument doc;

  // Add the current time and the data from the CAN Bus message to the JSON doc
  time_t now;
  time(&now);
  doc["time"] = now;
  doc["data"] = data;

  // Convert the JSON Doc to text
  String payload = String(doc.as<String>());

  // Send the message to the MQTT broker
  mqttClient.publish(topic.c_str(), payload.c_str(), true);

  // Check for alerts and warnings
  if (messageID == WARN_ID || messageID == ALERT_ID)
  {
    // Only send an email if the alrt or warning message being turned on
    if (data != 0)
    {
      Serial.println("Alert or Warning message received!!");

      // core.sendMessage(ALERT_ID, &data);

      // Send to email queue
      AlertData alertData;
      alertData.nodeID = nodeID;
      alertData.isWarning = messageID == WARN_ID ? 1 : 0;

      sendEmailToQueue(&alertData);

      // Send to alert queue in UIAlertData, in the first slot where isCleared is set to 1
      for (int i = 0; i < 50; i++)
      {
        if (alertQueue[i].isCleared == 1)
        {
          alertQueue[i].nodeID = nodeID;
          alertQueue[i].isWarning = 0;
          alertQueue[i].isSilenced = 0;
          alertQueue[i].isCleared = 0;
          baseStationState = 4;
          errorQueued = 1;
          delay(10);
          break;
        }
      }

      // xQueueSend(emailQueue, &alertData, portMAX_DELAY);
    }

    // TODO: Trigger hardware alert on the base station
  }

  // //Log the CAN Bus message to the SD card

  // Log the message to the SD card

  if (logMessage)
  {
    Serial.println("Logging message");
    writeLogData(SYSTEM_ID, BASESTATION_ID, String(baseStationFirmwareVersion), nodeID, messageID, data);
  }
  else
  {
    Serial.println("Not logging message");
  }

  delay(10);

  // mqttClient.loop();
}
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
void loop() //---------------------------------------------------Loop-----------------------------------------------------------------------------
{
  delay(100);
  emailClientLoop(email_recipient, email_recipient_name);

  // Go to screen saver after 5 seconds should no button be pressed
  if (baseStationState == 1)
  {
    if (millis() >= lastInput + 7000)
    {
      // Serial.println("Screen Saver Timeout");
      baseStationState = 0;
    }
  }

  if (digitalRead(0) == LOW)
  {
    if (digitalRead(11) == HIGH)
    {
      Serial.println("CANBus Off");
      screenSaverRunning = false;
      baseStationState = 5;
      MQTTdisconnect();
      digitalWrite(11, LOW);
    }
    else
    {
      Serial.println("CANBus On");
      screenSaverRunning = false;
      baseStationState = 0;
      xTaskCreatePinnedToCore(
          mqttLoop,   /* Function to implement the task */
          "mqttLoop", /* Name of the task */
          10000,      /* Stack size in words */
          NULL,       /* Task input parameter */
          1,          /* Priority of the task */
          &xMQTTloop, /* Task handle. */
          0);         /* Core where the task should run */
    }
    while (digitalRead(0) == LOW)
    {
      delay(10);
    }
  }
  if (digitalRead(21) == LOW)
  {
    screenSaverRunning = false;
    lastInput = millis();
    while (digitalRead(21) == LOW)
    {
      delay(10);
    }
  }
  if (digitalRead(47) == LOW)
  {
    // Serial.println("Button 47 pressed");
    screenSaverRunning = false;
    lastInput = millis();
    if (baseStationState == 4)
    {
    }
    else
    {
      if (baseStationState > 2)
      {
        baseStationState = 0;
      }
      else
      {
        baseStationState++;
      }
    }
    // Serial.println(baseStationState);
    // latching debounce
    while (digitalRead(47) == LOW)
    {
      delay(10);
    }
  }
  for (int i = 0; i < 50; i++)
  {
    if (alertQueue[i].isSilenced == 0)
    {
      baseStationState = 4;
    }
  }
  delay(25);
}

// function definitions ----------------------------------------------------------------------------------------------------------------------------

void saveConfigCallback()
{
  Serial.println("Running void saveConfigCallback()");
  Serial.println("Should save mqtt config");
  shouldSaveConfig = true;
  Serial.println("");
}



  
// function to handle internal messages from the MQTT broker
void handleInternalMessage(int messageID, uint64_t data)
{
  Serial.println("Running void handleInternalMessage(int messageID, uint64_t data)");
  switch (messageID)
  {
  case LED_BRIGHTNESS_MESSAGE_ID:
    Serial.println("LED Brightness message received");
    LEDBrightness_float = ((maxPWM / 100.0) * data);
    LEDBrightness = (int)LEDBrightness_float;
    pixels.setBrightness(LEDBrightness);
    pixels.show();
    Serial.println("LEDBrightness = ((maxPWM / 100.0) * data)" + String(LEDBrightness));
    Serial.println("");
    break;

  case RESET_ALERTS_MESSAGE_ID:
    Serial.println("Reset alerts message received");
    resetAlerts();
    break;

  case UPDATE_TIMEZONE_OFFSET_MESSAGE_ID:
    localTimeZoneOffset = data;
    localTimeZone = ("UTC+" + String(data));
    sendTimezoneOffsetMessage(data);
    break;

  default:
    Serial.println("Unknown message ID");
    break;
  }
  Serial.println("");
}

void sendTimezoneOffsetMessage(uint64_t data)
{
  Serial.println("Running void sendTimezoneOffsetMessage(uint64_t data)");
  twai_message_t timeZoneOffsetMessage = core.create_message(UPDATE_TIMEZONE_OFFSET_MESSAGE_ID, NODE_ID, &data);
  if (twai_transmit(&timeZoneOffsetMessage, 2000) == ESP_OK)
  {
    Serial.println("Sending Time Zone offset Message, queued for transmission");
    Serial.println("localTimeZoneOffset = " + String(localTimeZoneOffset));
    Serial.println("");
  }
  else
  {
    Serial.println("Failed to Send Time Zone offset Message");
    Serial.println("");
  }
}

// Function to send a message to the MQTT broker
void resetAlerts()
{
  Serial.println("Reset alerts message received");
  isErrors = 0;
  Serial.println("isErrors = 0");
  isNoErrors = 1;
  Serial.println("isNoErrors = 1");
  for (int i = 0; i < 50; i++)
  {
    alertQueue[i].isSilenced = 1;
  }
  SendMQTTMessage(SYSTEM_ID, BASESTATION_ID, NODE_ID, IS_ERRORS_MESSAGE_ID, isErrors);
  delay(100);
  SendMQTTMessage(SYSTEM_ID, BASESTATION_ID, NODE_ID, IS_NO_ERRORS_MESSAGE_ID, isNoErrors);
  delay(100);
  Serial.println("SednMQTTMessage(SYSTEM_ID, BASESTATION_ID, NODE_ID, IS_ERRORS_MESSAGE_ID, isErrors" + String(isErrors));
  Serial.println("SendMQTTMessage(SYSTEM_ID, BASESTATION_ID, NODE_ID, IS_NO_ERRORS_MESSAGE_ID, isNoErrors" + String(isNoErrors));
  Serial.println("Alerts reset mesages to MQTT sent to change the status of the Errors detected and No errors detected chip");
  Serial.println("");
}

// Function to send a message to the MQTT broker
void handleHistoryMessage(int nodeID, int messageID, uint64_t data)
{
  Serial.println("Running void handleHistoryMessage(int nodeID, int messageID, uint64_t data)");
  Serial.println("History message received for node: " + String(nodeID) + " message: " + String(messageID) + " hours: " + String(data));
  JsonDocument historyDoc;
  sendLogData(userID, SYSTEM_ID, BASESTATION_ID, nodeID, messageID, data, &mqttClient);
  Serial.println("History message sent to MQTT");
  Serial.println("");
}

// Function to send a message to the MQTT broker
void handleManifestMessage(JsonDocument &doc, byte *payload, unsigned int length)
{
  Serial.println("Running void handleManifestMessage(JsonDocument &doc, byte *payload, unsigned int length)");
  if (LittleFS.exists(manifestFileName))
  {
    Serial.println("Manifest file exists, removing old file");
    LittleFS.remove(manifestFileName);
    File manifestFile = LittleFS.open(manifestFileName, FILE_WRITE);
    manifestFile.write(payload, length);
    manifestFile.close();
  }
  else
  {
    Serial.println("Manifest file does not exist, creating new file");
    File manifestFile = LittleFS.open(manifestFileName, FILE_WRITE);
    manifestFile.write(payload, length);
    manifestFile.close();
  }

  Serial.println("Sending manifest data to MQTT");
  String manifestTopic = userID + "/manifestOut/" + String(SYSTEM_ID) + "/" + String(BASESTATION_ID);
  mqttClient.publish(manifestTopic.c_str(), doc.as<String>().c_str(), true);
  Serial.println("Manifest data sent to MQTT");
  Serial.println("");
}

/*----------------------------------------------Original function pre compartmetalization--------------------------------------------------------------



void receivedMQTTMessage(char *topic, byte *payload, unsigned int length) // Callback function for MQTT messages----------------------------------------------
{
  /*   Serial.print("Message arrived [");
    Serial.print(topic);
    Serial.print("] ");
    for (int i = 0; i < length; i++) {
      Serial.print((char)payload[i]);
    }
    Serial.println(); */

// Parse the topic to get the node ID and message ID with the format:
//  in/systemID/baseStationID/nodeID/messageID/

/*
String topicString = String(topic);
int index = 0;
index = topicString.indexOf("/", index);
String type = topicString.substring(0, index);
index = topicString.indexOf("/", index + 1);
index = topicString.indexOf("/", index + 1);
int nodeID = topicString.substring(index + 1, topicString.indexOf("/", index + 1)).toInt();
index = topicString.indexOf("/", index + 1);
int messageID = topicString.substring(index + 1, topicString.indexOf("/", index + 1)).toInt();

Serial.print("Type: ");
Serial.println(type);
Serial.print("Node ID: ");
Serial.println(nodeID);
Serial.print("Message ID: ");
Serial.println(messageID);

// Allocate the JSON document
JsonDocument doc;

// Parse the JSON object
DeserializationError error = deserializeJson(doc, payload);

// Test if parsing succeeds
if (error)
{
  Serial.print(F("deserializeJson() failed: "));
  Serial.println(error.c_str());
  Serial.println((char *)payload);
}
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

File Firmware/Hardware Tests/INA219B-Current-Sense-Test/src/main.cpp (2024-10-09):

#include <Arduino.h>

#include <Wire.h>
#include <Adafruit_INA219.h>

Adafruit_INA219 ina219(0x4A);

TwoWire wire = TwoWire(0);


void setup(void) 
{
  Serial.begin(115200);

  pinMode(11, OUTPUT);
  digitalWrite(11, HIGH);

  wire.setPins(9,10);
  
  delay(2000); // Give time to the serial monitor to start
    
  Serial.println("Hello!");
  
  // Initialize the INA219.
  // By default the initialization will use the largest range (32V, 2A).  However
  // you can call a setCalibration function to change this range (see comments).
  if (! ina219.begin(&wire)) {
    Serial.println("Failed to find INA219 chip");
    while (1) { delay(10); }
  }
  // To use a slightly lower 32V, 1A range (higher precision on amps):
  //ina219.setCalibration_32V_1A();
  // Or to use a lower 16V, 400mA range (higher precision on volts and amps):
  //ina219.setCalibration_16V_400mA();

  Serial.println("Measuring voltage and current with INA219 ...");
}

void loop(void) 
{
  float shuntvoltage = 0;
  float busvoltage = 0;
  float current_mA = 0;
  float loadvoltage = 0;
  float power_mW = 0;

  shuntvoltage = ina219.getShuntVoltage_mV();
  busvoltage = ina219.getBusVoltage_V();
  current_mA = ina219.getCurrent_mA();
  power_mW = ina219.getPower_mW();
  loadvoltage = busvoltage + (shuntvoltage / 1000);
  
  Serial.print("Bus Voltage:   "); Serial.print(busvoltage); Serial.println(" V");
  Serial.print("Shunt Voltage: "); Serial.print(shuntvoltage); Serial.println(" mV");
  Serial.print("Load Voltage:  "); Serial.print(loadvoltage); Serial.println(" V");
  Serial.print("Current:       "); Serial.print(current_mA); Serial.println(" mA");
  Serial.print("Power:         "); Serial.print(power_mW); Serial.println(" mW");
  Serial.println("");

  delay(2000);
}

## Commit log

2024-07-16 Added very basic CAN Bus, wifi and MQTT support
2024-07-19 Added basic MQTT to CAN bus message flow
2024-07-20 Working state for public broker
    [main.cpp]
2024-07-30 Bug fix for pointer issue with sending messages to CAN bus
    [main.cpp]
2024-09-21 Disable WiFi manager, working on email support(not working)
    [main.cpp]
2024-09-23 Fix bug were email client loop was interfering with MQTT message receiving
    [main.cpp]
2024-09-23 Move datalogging to library files, minor bug fixes and cleanup
    [main.cpp]
2024-09-24 Started log row parsing(not working)
    [main.cpp]
2024-10-07 Add device name to email alerts
2024-10-09 Update current sensor test
2024-10-10 New sd card pins, CAN power switch
2024-10-12 Move core CAN Bus code from node controller lib to base station code base
2024-10-12 Moved send CAN message code to main.cpp to fix 0 data bug
    [main.cpp]
2024-10-12 Bradens First Commit. Added BOOT Button functionality to toggle CANBus +24v.
2024-10-14 Cleaner fix for 0 data transmit bug
    [main.cpp]
2024-10-21 Pretty fucking broken. Got close to getting a LCD, but then it all fell apart. Commiting to save progress before going back to previous commit.
    [main.cpp]
2024-10-23 Add mqtt client loop to can bus message receive
2024-10-25 Dirty Mid Working on shit Commit. Sorry. Everythings working - Adding in custom current sense calibration currently (teehee)
2024-10-26 Move MQTT to task to fix TLS errors
    [main.cpp]
2024-10-26 Watch dog timer bug fixes
    [main.cpp]
2024-10-26 Revert "Full on FUBARed."
    This reverts commit 062bc0d9bff85a3dc3fed44e9f079f3777d67a8d.
    [main.cpp]
2024-10-28 Another Day, Another Dollar. Screensaver will save our OLED now. Not sure if burn in was a concern - but its not now.
    [main.cpp]
2024-10-30 Add delay for watch dog timer issues
    [main.cpp]
2024-11-03 End of day Saturday. Things are working, though history is crashing the base station......
    [main.cpp]
2024-11-04 Screen saver starts on its own. gotta add in more BIOS stuff, and the utility screen. Beyond that its good now.
    Button 0 turns off the canbus network - and will restart the connection after aswell.
2024-11-09 I have fixed all of the bugs. Or at least I'm about too!
    Think I fixed the random watch dog loop were getting in.
    Touched up other stuff im sure.
    [main.cpp]
2024-11-09 Bug in error que handeling. Currently will not save more then one error after silencing
    [main.cpp]
2024-11-09 Code in a basically final state. serial.print statements still running.
2024-11-09 most serial prints commented out.
    code in a ready to sell state. Find those errors and bugs team!
    [main.cpp]
2024-11-15 Added count to unsilenced alert screen so it doesn't feel like you are doing nothing when clearing errors
    [main.cpp]
2024-11-20 new settings screen for Base Station UI. CANBus toggle, and two no function screens implemented so far. Untested.
2024-11-20 It can now mute the buzzer too! I cannot make it shut down. I think restarting the ESP is the best I can do.
    [main.cpp]
2024-11-20 It now has Dark Mode as well. Modifies the screen saver screens to be... dark. The logo should time out after 5 seconds. No LEDs.
2024-11-20 System restart page added. increased screen saver time out to 7 seconds, as restarts behind a 5 second button hold.
    This is the last operation to add i think!
2024-11-20 More UI Bug fixing.
    Good push.
    [main.cpp]
2024-12-08 Add base station Altuim project
    [ProjectFishWorks-Schematic.SchLib]
2024-12-08 Re-add Altuim Project without repo
    [Base Station v1.GBL, Base Station v1.GBO, Base Station v1.GBS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]
2024-12-31 Added globalvariable for LEDBrightness
2025-01-01 Added brightness controll and alert reset
    [main.cpp]
2025-01-18 Add basic auth0 device flow(MQTT login not working)
    [main.cpp]
2025-01-19 Added error notification and reseting via App. time setting and time zones via app. Added time to OLED display , but stuck on screensaver. int lastaposition not incrementing
    [main.cpp]
2025-01-21 Logo moves to position oif current second in screensaver
2026-01-01 Merged fixed compile errors
    [main.cpp]
2026-01-01 Fix topic string error in manifest
    [main.cpp]
2026-01-08 Reduce MQTT payload buffer size to attempt to reduce long term memory errors
    [main.cpp]
